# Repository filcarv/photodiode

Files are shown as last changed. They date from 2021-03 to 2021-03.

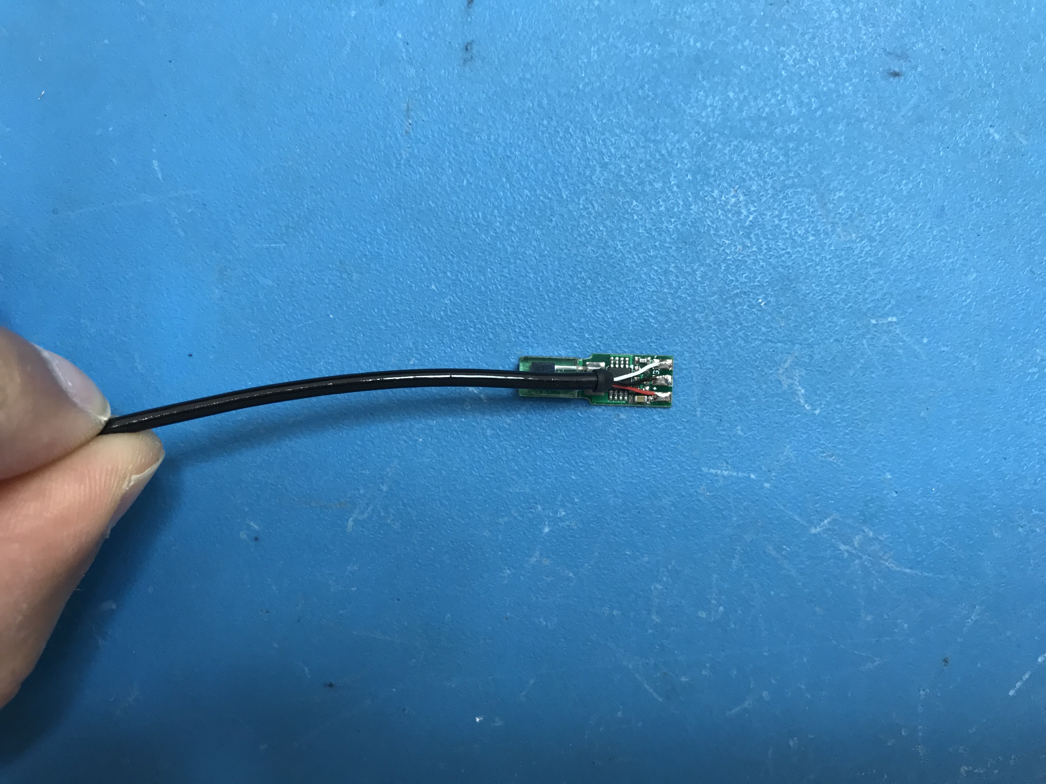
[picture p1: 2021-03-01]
Pics/IMG-5027.jpg

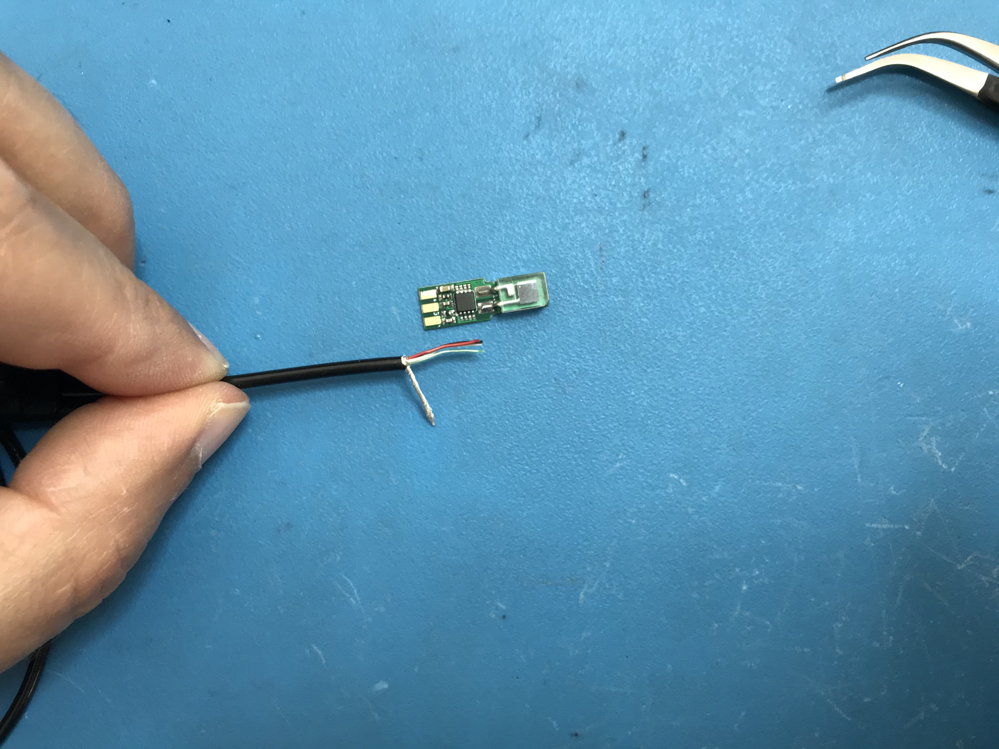
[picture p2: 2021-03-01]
Pics/IMG-5011.jpg

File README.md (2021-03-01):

# Photodiode

General photodiode to synchronize screens (or other light source) with behavior.

# Licensing

The code, designs, documentation, and photos available in this repository is free: you can redistribute it and/or modify it under the terms of the used license.
Each subdirectory will contain a license or, possibly, a set of licenses if it involves both hardware and software. Check files named LICENSE.

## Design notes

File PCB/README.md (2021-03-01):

# Photodiode

## Licensing

The designs, documentation, and photos available in this repository are free: you can redistribute it and/or modify it under the terms of the used license.
Check file named LICENSE.

Copyright Filipe Carvalho 2020-2021

<br />This work is licensed under a <a rel="license" href="http://creativecommons.org/licenses/by-nc-sa/3.0/igo/">Creative Commons Attribution-NonCommercial-ShareAlike 3.0 IGO License</a>.

If your are interested in obtaining a license to sell this device, please contact filipe@open-ephys.org

[1]: https://docs.google.com/spreadsheets/d/1aobmmEzBDethzIlrm1eg0eYkBqlyX3s9WbA9KgRwVQI/edit?usp=sharing

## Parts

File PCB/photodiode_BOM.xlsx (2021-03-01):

Internal PN | Part(s) | Qtty. | Description | Type | Distributor | Part Number
 | IC1 | 1 | IC OPAMP GP 28MHZ RRO MSOP | SMD | Farnell | 2112576
 | R1 | 1 | RES SMD 499K OHM 1% 1/16W 0402 | SMD | Mouser | 71-CRCW0402499KFKEDC
 | R1 | 1 | RES SMD 62K OHM 1% 1/16W 0402 | SMD | Mouser | 71-CRCW040262K0FKED
 | R1 | 1 | RES SMD 124K OHM 1% 1/16W 0402 | SMD | Mouser | 71-CRCW0402-124K-E3
 | R1 | 1 | RES SMD 249K OHM 1% 1/16W 0402 | SMD | Mouser | 71-CRCW0402-249K-E3
 | R1 | 1 | RES SMD 1M OHM 1% 1/16W 0402 | SMD | Mouser | 71-CRCW04021M00FKEDC
 | R1 | 1 | RES SMD 2M OHM 1% 1/16W 0402 | SMD | Mouser | 71-CRCW04022M00FKEDC
 | C1 | 1 | CAP CER 0.5PF 50V C0G/NP0 0402 | SMD | Mouser | 81-GRM1555C1HR50WA1D
 | C2 | 1 | CAP CER 100nF 10V X5R 0402 | SMD | Mouser | 710-885012105018
 | C3 | 1 | CAP CER 10uF 10V ±10% X5R 0603 | SMD | Mouser | 81-GRM188R61A106KE9D
 | L1 | 1 | FERRITE BEAD 1 KOHM 0402 1LN | SMD | Mouser | 810-MMZ1005S102CT000
 | Sensor | 1 | PHOTODIODE BLUE 8.02MM SQ CLEAR | TH | Digikey | PDB-C156-ND
 | - | 1 | Infrared filter | - | Amazon | Link (https://www.amazon.es/gp/product/B07C6TL1BX/ref=ppx_yo_dt_b_asin_title_o00_s00?ie=UTF8&psc=1)
 | - | 1 | Rubber pad | - | Amazon | Link (https://www.amazon.com/gp/product/B01K7JFXAA/ref=ppx_yo_dt_b_asin_title_o05_s00?ie=UTF8&psc=1)
 | - | 1 | 3D Black Natural Versatile Plastic | - | Shapeways | IBL_photodiode_holder_v1.1
 | - | 1 | 3D Black Natural Versatile Plastic | - | Shapeways | IBL_photodiode_IR_filter_v1.1
 | - | 1 | 3D Black Natural Versatile Plastic | - | Shapeways | IBL_Frame2TTL_IR_Shield - Wedge v1.0
 | - | 1 | 3D Black Natural Versatile Plastic | - | Shapeways | IBL_Frame2TTL_BackSide
 | - | 1 | 6-32 nut | - | Digikey | 36-4701-ND
 | - | 1 | 6-32 Thumb screw | - | Digikey | 36-2405-ND
 | - | 1 | Cable OD: 2.20+/-0.16mm | - | Industrifil | TPU-3219.04B
 | - | 1 | Micro-Miniature, 4 Contacts, Plug, I/O | - | Farnell | 2554951
 | - | 0.08333333333 | Heat shrink | - | Farnell | 1259197
 |  | 6 | Different SMD components
 |  | 6 | SMD components
 |  | 1 | Different TH components
 |  | 1 | TH components
 |  | top | Assembly components

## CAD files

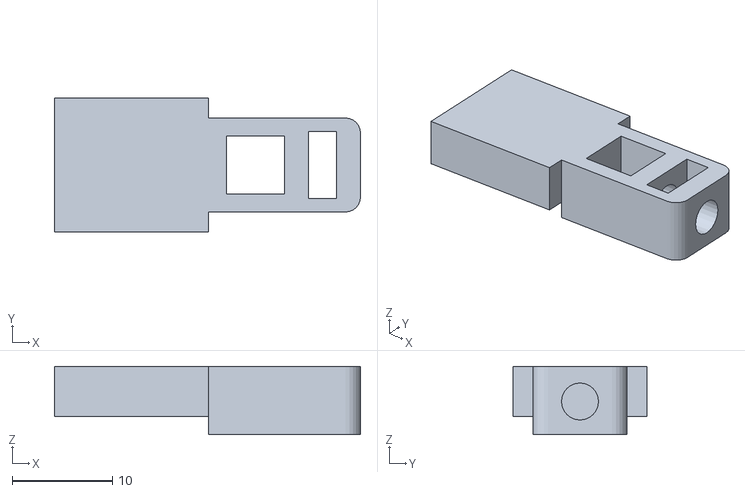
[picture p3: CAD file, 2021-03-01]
3D/IBL_Frame2TTL_BackSide.stl
30.6 x 13.4 x 6.80

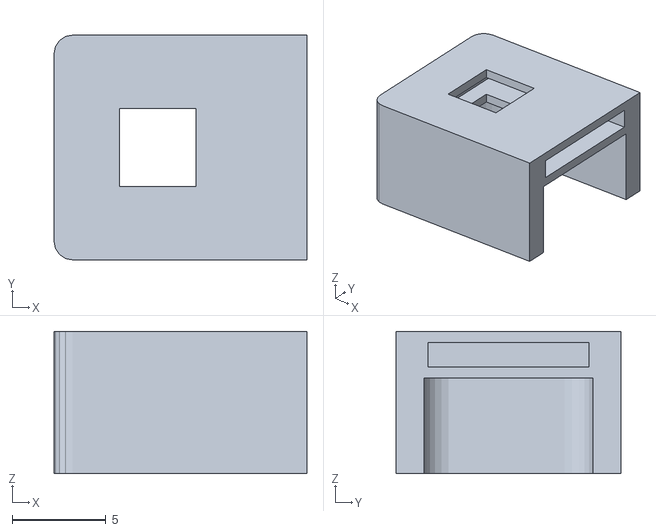
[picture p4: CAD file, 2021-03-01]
3D/IBL_photodiode_IR_filter_v1.1.stl
13.5 x 12.0 x 7.60

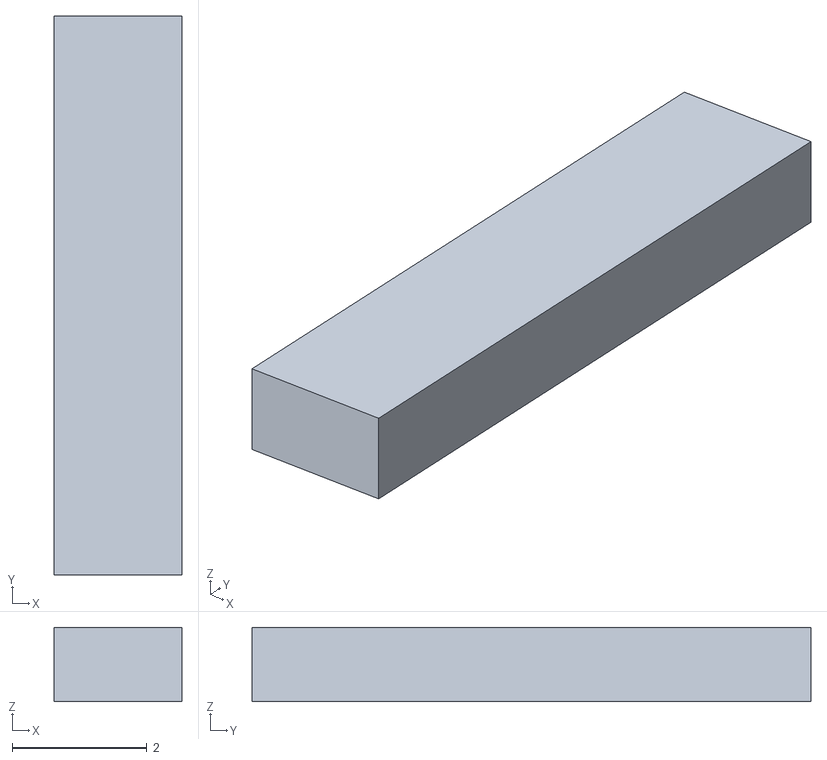
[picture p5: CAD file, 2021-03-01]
3D/IBL_Frame2TTL_IR_Shield - Wedge v1.0.stl
1.90 x 8.30 x 1.10

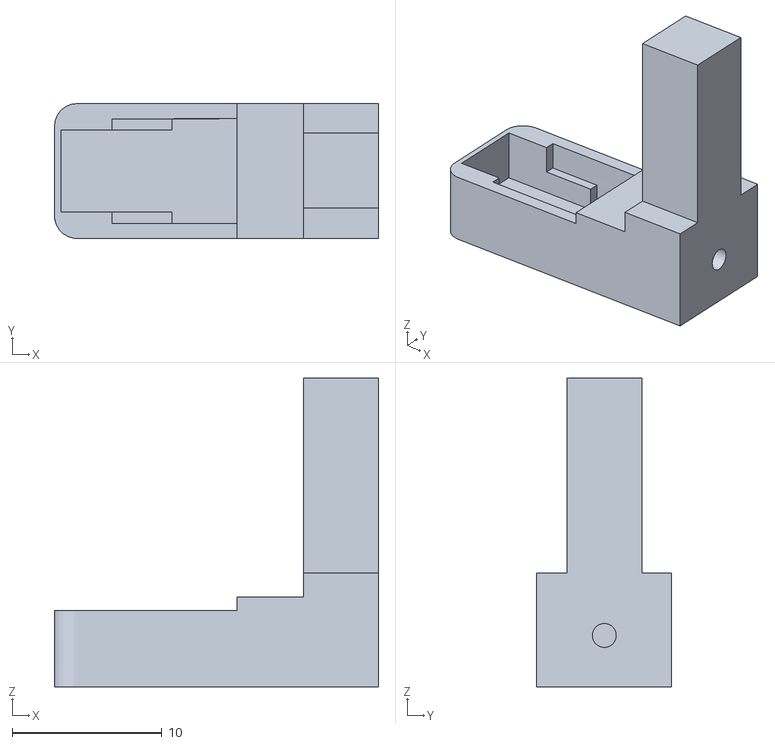
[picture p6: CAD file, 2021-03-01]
3D/IBL_photodiode_holder_v1.2.stl
21.6 x 9.00 x 20.6

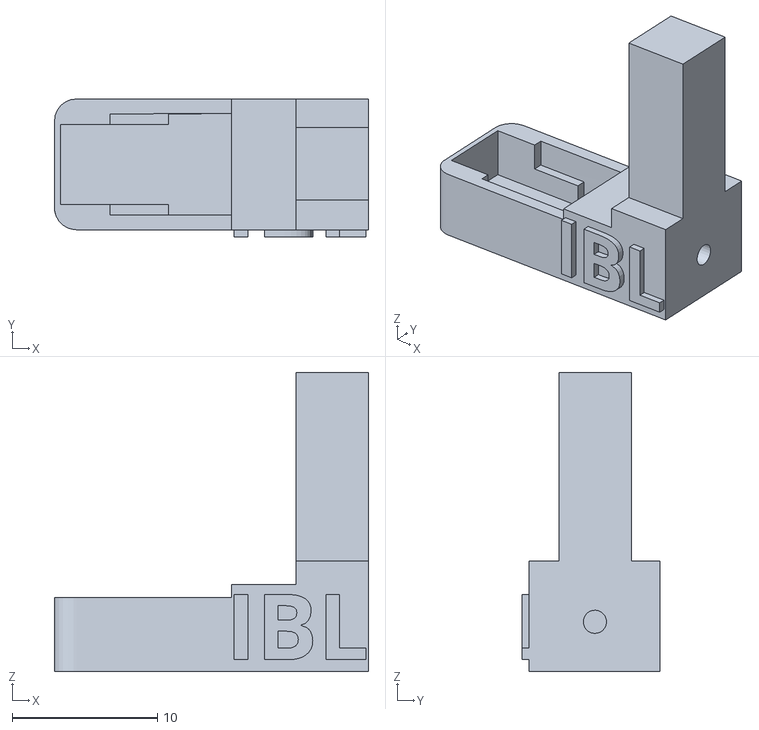
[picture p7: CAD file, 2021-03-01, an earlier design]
3D/IBL_photodiode_holder_v1.1.stl
21.6 x 9.50 x 20.6

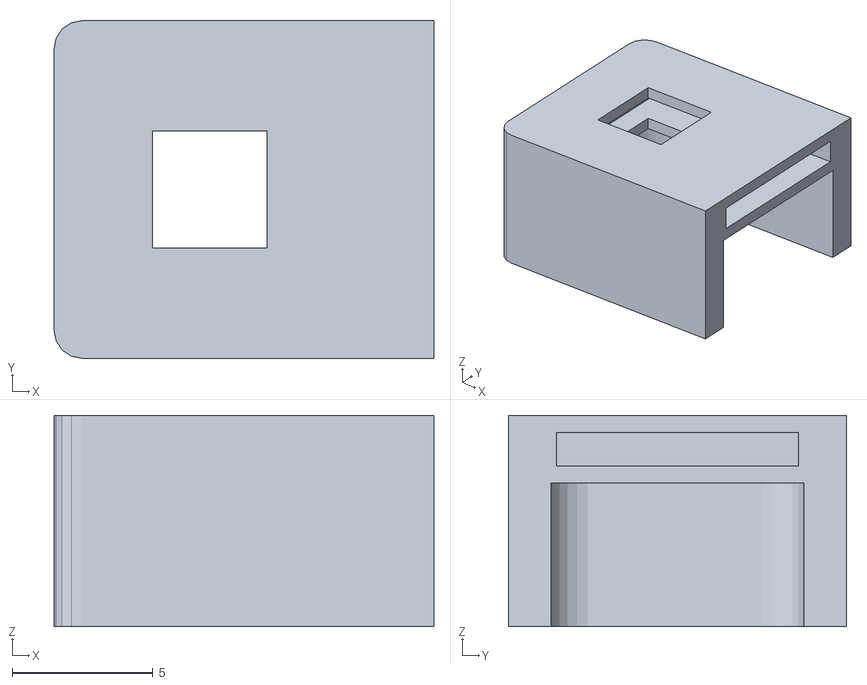
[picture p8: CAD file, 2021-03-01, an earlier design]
3D/IBL_photodiode_IR_filter_v1.0.stl
13.5 x 12.0 x 7.50

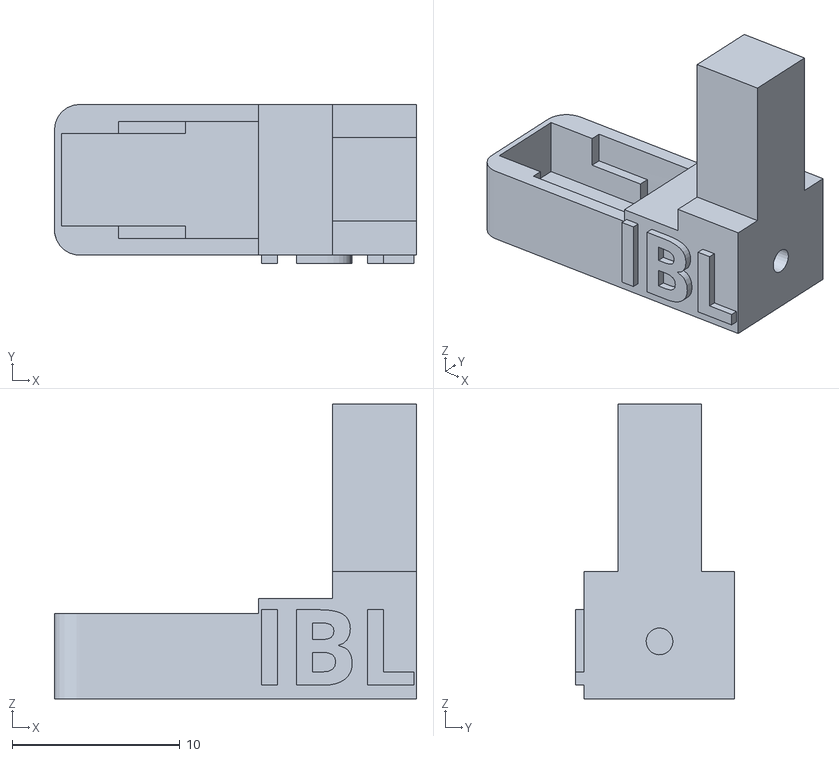
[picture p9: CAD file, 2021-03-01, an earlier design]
3D/IBL_photodiode_holder_v1.0.stl
21.6 x 9.50 x 17.6

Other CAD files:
3D/IBL_photodiode_IR_filter_v1.0.skp
3D/IBL_photodiode_IR_filter_v1.1.skp
3D/IBL_photodiode_holder_v1.0.skp
3D/IBL_photodiode_holder_v1.1.skp

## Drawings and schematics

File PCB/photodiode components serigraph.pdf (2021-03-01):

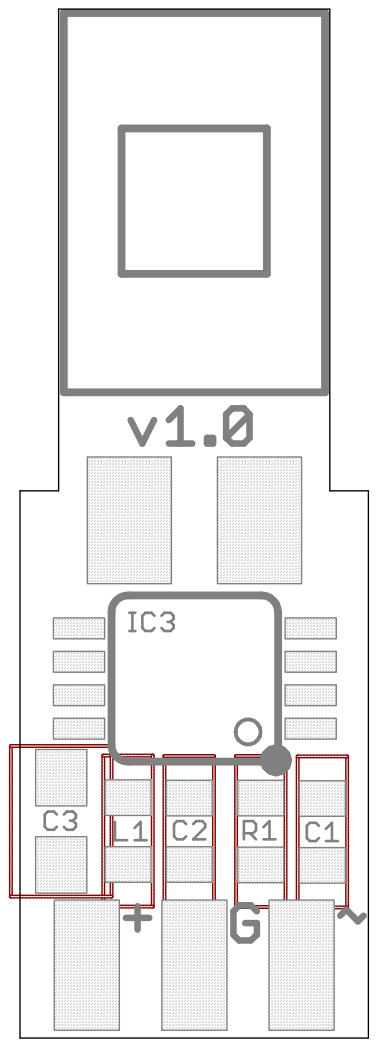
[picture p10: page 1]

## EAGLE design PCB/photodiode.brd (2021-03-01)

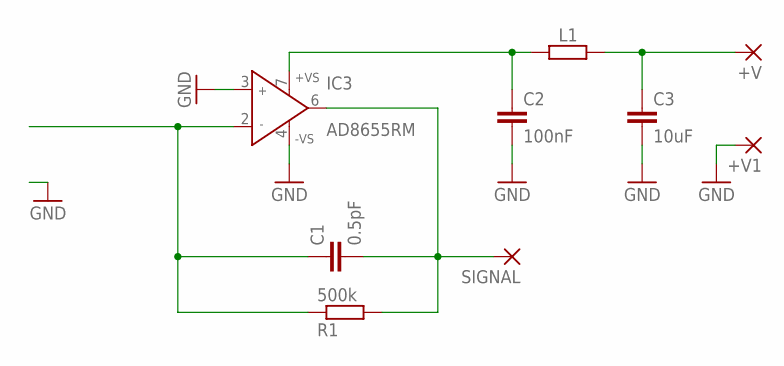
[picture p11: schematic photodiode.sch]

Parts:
+V, +V1: WIREPADSMD1,27-254; SMD1,27-2,54
C1: 0.5pF; C0402
C2: 100nF; C0402
C3: 10uF; C0603
IC3: AD8655RM; MSOP08
L1: 1k@100M; R0402
R1: 500k; R0402
SIGNAL: WIREPADSMD1,27-254; SMD1,27-2,54

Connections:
AMP_OUT: C1.2, IC3.6 (OUT), R1.2, SIGNAL.1
GND: +V1.1, C2.2, C3.2, IC3.3 (IN+), IC3.4 (-VS)
KATODE: C1.1, IC3.2 (IN-), R1.1
SUPPLY: C2.1, IC3.7 (+VS), L1.2
SUPPLY_INPUT: +V.1, C3.1, L1.1

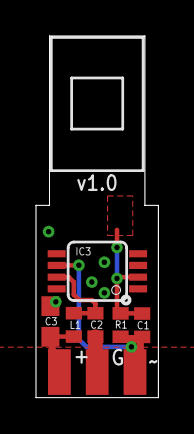
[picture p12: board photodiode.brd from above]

Board: 2 copper layers, 6.8 x 20.1 mm, 9 parts (0 on the bottom side), 5 nets.

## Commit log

2021-03-01 Added PCB files and license.
    [photodiode.brd, photodiode.sch, photodiode_BOM.xlsx]
2021-03-01 Added 3D files.
    [IBL_Frame2TTL_BackSide.stl, IBL_Frame2TTL_IR_Shield - Wedge v1.0.stl, IBL_photodiode_IR_filter_v1.0.skp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]
2021-03-01 Added some assembly photos.
